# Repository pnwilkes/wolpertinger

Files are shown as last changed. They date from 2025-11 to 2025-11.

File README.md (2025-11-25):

# Wolpertinger

Wolpertinger is an optical tremolo effect inspired by David Rolo’s **Twin Peaks Tremolo**.  
It can be built in **mono** or **stereo**, with classic or harmonic tremolo modes, and supports an optional external LFO input for advanced modulation setups.

---

## Features

- Optical tremolo (mono or stereo)
- Onboard sine-wave LFO with **Speed** and **Depth** controls
- Independent tone control per channel
- Relay-based true bypass
- **Classic/Harmonic mode:** modulate highs and lows in-phase or out-of-phase
- **Mono/Stereo operation:** optional 180° LFO phase shift between channels (stereo version only)
- External LFO input for complex or synchronized modulation

---

## Build Instructions

Solder components starting with the lowest-profile parts and ending with the tallest.  
It is recommended to socket all **ICs, transistors, and relays**.

> **Note:** Always verify component orientation (diodes, electrolytics, ICs, LEDs).

To build the mono version, just do not populate the left channel. If you want to safe space, you can entirely cut it off the PCB along the left white line.

### Schematic

**TODO**

### PCB

**TODO**

### Bill of Materials (BOM)

**TODO**

---

## Calibration

This circuit includes several trim potentiometers that must be adjusted in a specific order.  
All trimmers are safe to rotate across their entire range—incorrect settings may sound odd but will not damage the circuit.

Order of calibration:
1. **Offset**
2. **Depth**
3. **Gain**

---

### 1. Offset

**TODO: Add details once available**

---

### 2. Depth

Perform the following steps for **each channel**:

1. Set the **Depth knob** (front panel) to maximum.
2. Set the **Speed knob** to minimum.
3. For each *Depth trimmer*:
   1. Turn the trimmer fully counterclockwise.
   2. Slowly turn it clockwise until the signal briefly cuts out at the peaks of the LFO.
      - Feeding a test tone into the pedal makes this much easier.

---

### 3. Gain

Once Offset and Depth are set:

1. Set the **Depth knob** fully counterclockwise so the modulation is effectively off.
2. Adjust the **Gain trimmer** until the effect's output level matches the bypass level.
   - You can verify this by repeatedly switching the bypass relay on and off.

---

## License

**TODO**

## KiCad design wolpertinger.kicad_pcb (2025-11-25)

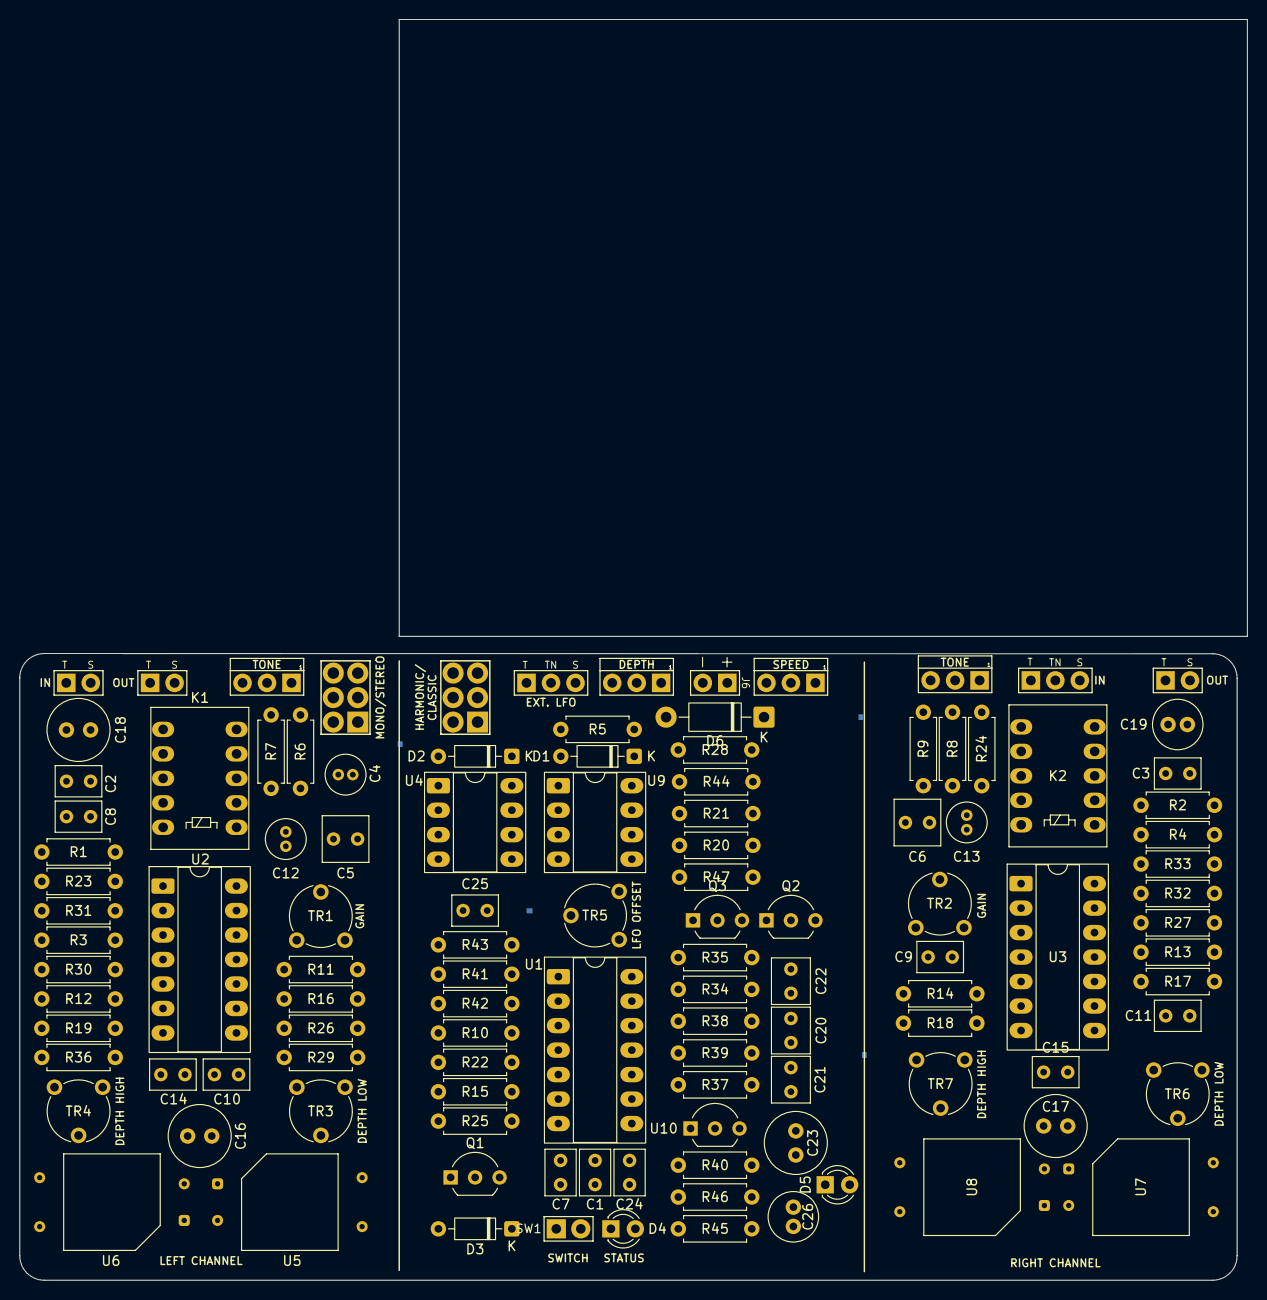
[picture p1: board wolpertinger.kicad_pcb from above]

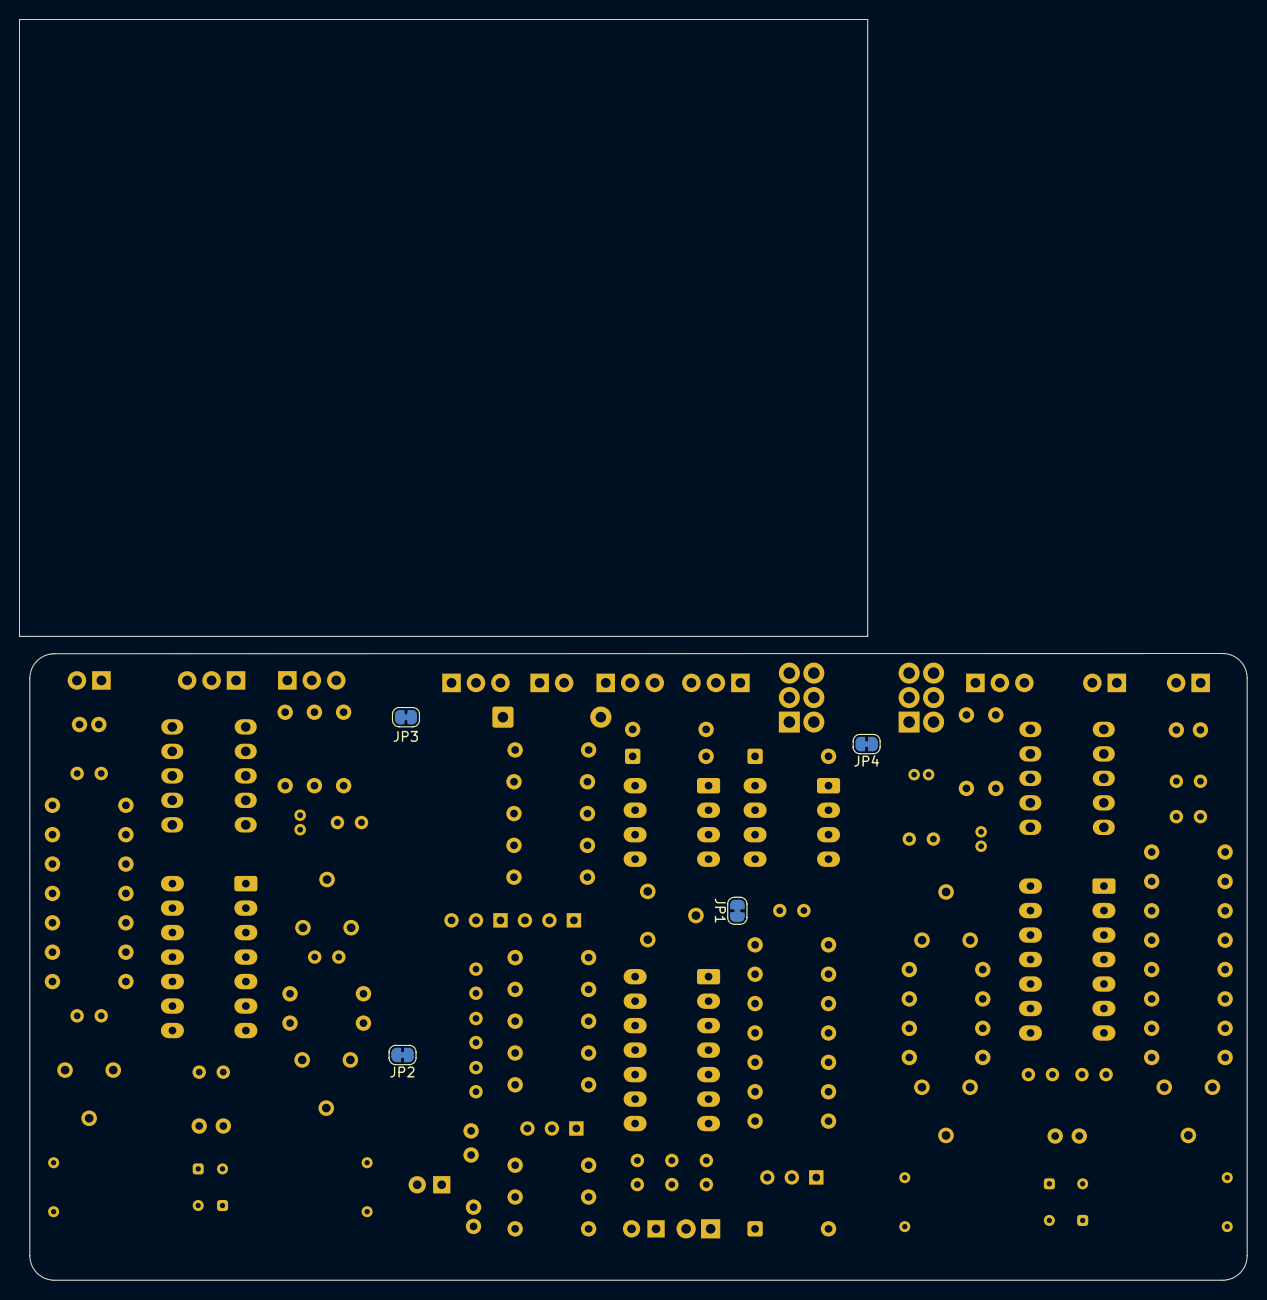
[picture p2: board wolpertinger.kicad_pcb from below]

Board: 2 copper layers, 127.4 x 130.8 mm, 118 parts (4 on the bottom side), 82 nets, no tracks yet.

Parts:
C1, C2, C3, C7, C14, C15, C24, C25: 100nF; C_Rect_L4.6mm_W3.0mm_P2.50mm_MKS02_FKP02
C4, C12, C13: 10uF; C_Radial_D4.0mm_H7.0mm_P1.50mm
C5, C6: 470nF; C_Rect_L4.6mm_W4.6mm_P2.50mm_MKS02_FKP02
C8, C9: 6.8nF; C_Rect_L4.6mm_W3.0mm_P2.50mm_MKS02_FKP02
C10, C11: 4.7nF; C_Rect_L4.6mm_W3.0mm_P2.50mm_MKS02_FKP02
C16, C17, C23: 100uF; C_Radial_D6.3mm_H11.0mm_P2.50mm
C18: 47uF; C_Radial_D6.3mm_H11.0mm_P2.50mm
C19, C26: 47uF; C_Radial_D5.0mm_H11.0mm_P2.00mm
C20, C21, C22: 330nF; C_Rect_L4.6mm_W3.8mm_P2.50mm_MKS02_FKP02
D1, D2: BAT42; D_DO-35_SOD27_P7.62mm_Horizontal
D3: 1N4148; D_DO-35_SOD27_P7.62mm_Horizontal
D4: STATUS LED; LED_D3.0mm
D5: TBD; LED_D3.0mm
D6: 1N4001; D_DO-41_SOD81_P10.16mm_Horizontal
J1: RIGHT IN; Switched Mono Jack
J2: LEFT IN; TWO_PADS
J3: EXT LFO; Switched Mono Jack
J4: LEFT OUT; TWO_PADS
J5: RIGHT OUT; TWO_PADS
J6: Jack-DC; BATTERY
JP1, JP2, JP3, JP4: SolderJumper-2_P1.3mm_Bridged_RoundedPad1.0x1.5mm
K1, K2: FRT5; Relay_DPDT_FRT5
Q1: BC549; TO-92_Inline_Wide
Q2, Q3: BC547; TO-92_Inline_Wide
R1, R2, R3, R4, R10, R23, R24: 1M; R_Axial_DIN0207_L6.3mm_D2.5mm_P7.62mm_Horizontal
R5, R15, R20, R21, R25, R37, R41, R42, R43: 10k; R_Axial_DIN0207_L6.3mm_D2.5mm_P7.62mm_Horizontal
R6, R7, R8, R9, R11, R12, R13, R14: 15K; R_Axial_DIN0207_L6.3mm_D2.5mm_P7.62mm_Horizontal
R16, R17, R18, R19: 51K; R_Axial_DIN0207_L6.3mm_D2.5mm_P7.62mm_Horizontal
R22, R28, R39: 4k7; R_Axial_DIN0207_L6.3mm_D2.5mm_P7.62mm_Horizontal
R26, R27, R40: 33r; R_Axial_DIN0207_L6.3mm_D2.5mm_P7.62mm_Horizontal
R29, R36, R44, R47: 100r; R_Axial_DIN0207_L6.3mm_D2.5mm_P7.62mm_Horizontal
R30, R31, R32, R33, R45, R46: 100k; R_Axial_DIN0207_L6.3mm_D2.5mm_P7.62mm_Horizontal
R34: 22k; R_Axial_DIN0207_L6.3mm_D2.5mm_P7.62mm_Horizontal
R35: 3M3; R_Axial_DIN0207_L6.3mm_D2.5mm_P7.62mm_Horizontal
R38: TBD; R_Axial_DIN0207_L6.3mm_D2.5mm_P7.62mm_Horizontal
RV1: 100k B; 16MM_PADS.1
RV2, RV3: 10k B; 16MM_PADS.1
RV4: 100k C; 16MM_PADS.1
SW1: ON/OFF; SPST
SW2: DPDT MONO/STEREO; DPDT
SW3: DPDT HARMONIC/TREMOLO; DPDT
TR1, TR2: VOLUME Trim 50k; Potentiometer_Piher_PT-6-V_Vertical
TR3: LO L Trim 5k; Potentiometer_Piher_PT-6-V_Vertical
TR4: HI L Trim 5k; Potentiometer_Piher_PT-6-V_Vertical
TR5: OFFSET Trim 25k; Potentiometer_Piher_PT-6-V_Vertical
TR6: LO R Trim 5k; Potentiometer_Piher_PT-6-V_Vertical
TR7: HI R Trim 5k; Potentiometer_Piher_PT-6-V_Vertical
U1: 4093; CERDIP-14_W7.62mm_SideBrazed_LongPads_Socket
U2, U3: TL074; CERDIP-14_W7.62mm_SideBrazed_LongPads_Socket
U4, U9: NE5532; DIP-8_W7.62mm_Socket_LongPads
U5, U6, U7, U8: VTL5C; PerkinElmer_VTL5C
U10: L78L05_TO92; TO-92_Inline_Wide

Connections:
9V: C1.1, D3.1 (K), D4.2 (A), D6.1 (K), J6.2, K1.1, K2.1, R26.1, R27.1, R40.1, U1.14 (Vdd)
BYPASS L: J2.T, K1.2, K1.7
BYPASS R: J1.T, K2.4, K2.9
GND: D6.2 (A), J6.1, JP1.2 (B), JP2.2 (B), JP3.2 (B), JP4.2 (B)
GND1: C14.1, C16.2, C18.2, J2.S, J4.S, JP4.1 (A), K1.9, R1.2, R23.2, R31.2, U2.11 (V-)
GND2: C15.1, C17.2, C19.2, J1.S, J5.S, JP3.1 (A), K2.2, R2.2, R24.2, R33.2, U3.11 (V-)
GND3: C23.2, C24.1, C26.2, D2.2 (A), D5.1 (K), J3.S, JP2.1 (A), Q2.3 (E), R28.2, R34.2, R39.2, R46.2, TR5.3, U4.4 (V-), U5.1 (-), U6.1 (-), U7.1 (-), U8.1 (-), U9.4 (V-)
GND4: C1.2, C7.2, JP1.1 (A), Q1.3 (E), U1.7 (Vss), U1.8, U1.9, U1.12, U1.13
LFO: C25.1, J3.TN, R43.1, U9.1
LFO out: R21.1, SW2.3 (C), SW2.4 (A), SW3.3 (C), U9.7
LFO out inv: R20.2, R47.1, SW2.1 (A), SW2.6 (C), SW3.1 (A), U4.6 (-), U4.7
MONO IN: C4.2, J1.TN
unnamed: C2.1, K1.8, R1.1
unnamed: C3.1, K2.3, R2.1
unnamed: C5.2, R6.2, R7.2
unnamed: C6.2, R8.2, R9.2
unnamed: C8.1, R7.1, RV2.3
unnamed: C8.2, R12.1
unnamed: C9.1, R9.1, RV3.3
unnamed: C9.2, R14.1
unnamed: C10.2, R16.2, U2.8, U5.3
unnamed: C11.2, R17.2, U3.8, U7.3
unnamed: C12.1, TR1.1, TR1.2, U2.14
unnamed: C12.2, K1.4, R23.1
unnamed: C13.1, TR2.1, TR2.2, U3.1
unnamed: C13.2, K2.7, R24.1
unnamed: C20.1, C22.2, R34.1
unnamed: C20.2, C21.2, RV4.1, RV4.2
unnamed: D1.2 (A), D2.1 (K), R5.2, RV1.1
unnamed: D3.2 (A), K1.10, K2.10, Q1.1 (C), R25.1
unnamed: D4.1 (K), R25.2
unnamed: D5.2 (A), U10.2 (GND)
unnamed: J3.T, R5.1
unnamed: J4.T, K1.3
unnamed: J5.T, K2.8
unnamed: Q1.2 (B), R22.2
unnamed: C22.1, Q2.2 (B), R35.2
unnamed: Q2.1 (C), Q3.2 (B), R35.1, R37.2
unnamed: C21.1, Q3.3 (E), R38.1
unnamed: R6.1, R11.1, RV2.1
unnamed: R8.1, R13.1, RV3.1
unnamed: R15.2, U1.3
unnamed: R18.1, U3.7, U8.3
unnamed: R19.1, U2.7, U6.3
unnamed: R28.1, RV4.3
unnamed: R29.2, TR3.1, TR3.2
unnamed: R36.2, TR4.1, TR4.2
unnamed: R38.2, R39.1, R42.2
unnamed: R41.2, TR5.2
unnamed: R44.2, TR6.1, TR6.2
unnamed: R47.2, TR7.1, TR7.2
unnamed: C7.1, R10.1, SW1.1 (A)
unnamed: R15.1, SW1.2 (B), U1.5, U1.6
unnamed: SW2.2 (B), SW3.6 (C)
unnamed: R36.1, SW2.5 (B), SW3.4 (A)
unnamed: R44.1, SW3.2 (B)
unnamed: R29.1, SW3.5 (B)
unnamed: C2.2, R3.2, U2.3 (+)
unnamed: C4.1, C5.1, U2.1, U2.2 (-)
unnamed: R12.2, R19.2, U2.6 (-)
unnamed: C10.1, R11.2, R16.1, U2.9 (-)
unnamed: TR1.3, U2.13 (-), U5.4, U6.4
unnamed: TR2.3, U3.2 (-), U7.4, U8.4
unnamed: R14.2, R18.2, U3.6 (-)
unnamed: C11.1, R13.2, R17.1, U3.9 (-)
unnamed: C3.2, R4.2, U3.12 (+)
unnamed: C6.1, U3.13 (-), U3.14
unnamed: RV1.2, U4.5 (+)
unnamed: C25.2, R41.1, R42.1, R43.2, U9.2 (-)
unnamed: R20.1, R21.2, U9.6 (-)
unnamed: C23.1, R40.2, U10.3 (VI)
ON/OFF: R10.2, R22.1, U1.1, U1.2, U1.4
V1: C14.2, C16.1, R26.2, R30.1, U2.4 (V+)
V2: C15.2, C17.1, R27.2, R32.1, U3.4 (V+)
V3: C24.2, D1.1 (K), Q3.1 (C), R37.1, R45.1, TR5.1, U4.8 (V+), U9.8 (V+), U10.1 (VO)
Vref1: C18.1, R3.1, R30.2, R31.1, RV2.2, U2.5 (+), U2.10 (+), U2.12 (+)
Vref2: C19.1, R4.1, R32.2, R33.1, RV3.2, U3.3 (+), U3.5 (+), U3.10 (+)
Vref3: C26.1, R45.2, R46.1, RV1.3, U9.3 (+), U9.5 (+)
hiL: TR4.3, U6.2 (+)
hiR: TR7.3, U8.2 (+)
loL: TR3.3, U5.2 (+)
loR: TR6.3, U7.2 (+)

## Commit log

2025-09-25 Init kicad
    [wolpertinger.kicad_pcb, wolpertinger.kicad_sch]
2025-09-25 add gitignore and schematic cleanup
    [wolpertinger.kicad_sch]
2025-09-25 Add second channel and true bypass relay switching
    [wolpertinger.kicad_sch]
2025-09-25 section cleanup
    [wolpertinger.kicad_sch]
2025-09-25 Added PCB, Footprint cleanup
    [wolpertinger.kicad_pcb, wolpertinger.kicad_sch]
2025-09-25 Add footprints
    [wolpertinger.kicad_pcb, wolpertinger.kicad_sch]
2025-09-26 add power supply
    [wolpertinger.kicad_pcb, wolpertinger.kicad_sch]
2025-09-26 add different power supply grounds
    [wolpertinger.kicad_pcb, wolpertinger.kicad_sch]
2025-09-28 Add internal LFO
    [wolpertinger.kicad_pcb, wolpertinger.kicad_sch]
2025-09-28 cleanup power supply, add lfo voltage offset
    [wolpertinger.kicad_pcb, wolpertinger.kicad_sch]
2025-10-14 add custom part libary and add mode switch
    [wolpertinger.kicad_pcb, wolpertinger.kicad_sch]
2025-10-19 remove hi and low only mode in favor of simpler switches
    [wolpertinger.kicad_pcb, wolpertinger.kicad_sch]
2025-10-19 Add in mono to stereo out option
    [wolpertinger.kicad_sch]
2025-10-19 Add Footprints pt1
    [wolpertinger.kicad_sch]
2025-10-19 update pcb
    [wolpertinger.kicad_pcb]
2025-10-19 Add LED footprint
    [wolpertinger.kicad_sch]
2025-10-19 Add DC Jk Footprint
    [wolpertinger.kicad_sch]
2025-10-19 Add capacitors footprint
    [wolpertinger.kicad_sch]
2025-10-19 Update jack footprints
    [wolpertinger.kicad_sch]
2025-10-20 fix footprint pad errors
    [wolpertinger.kicad_pcb]
2025-10-21 Left channel layout
    [wolpertinger.kicad_pcb, wolpertinger.kicad_sch]
2025-10-21 Right channel
    [wolpertinger.kicad_pcb]
2025-10-31 populate pcb
    [wolpertinger.kicad_pcb, wolpertinger.kicad_sch]
2025-11-02 layout work
    [wolpertinger.kicad_pcb, wolpertinger.kicad_sch]
2025-11-02 verifiy film cap footprints and transistor footprints
    [wolpertinger.kicad_pcb]
2025-11-02 fix short
    [wolpertinger.kicad_pcb]
2025-11-02 add wide transistor footprint
    [wolpertinger.kicad_sch]
2025-11-17 minor position adjustments
    [wolpertinger.kicad_pcb]
2025-11-23 parts aligning pt1
    [wolpertinger.kicad_pcb]
2025-11-25 GND improvements
    [wolpertinger.kicad_pcb, wolpertinger.kicad_sch]
